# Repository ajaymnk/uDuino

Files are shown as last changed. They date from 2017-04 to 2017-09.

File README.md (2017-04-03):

# uDuino
Arduino compatible AVR Development Board

#### Top Layer
<p align="center">
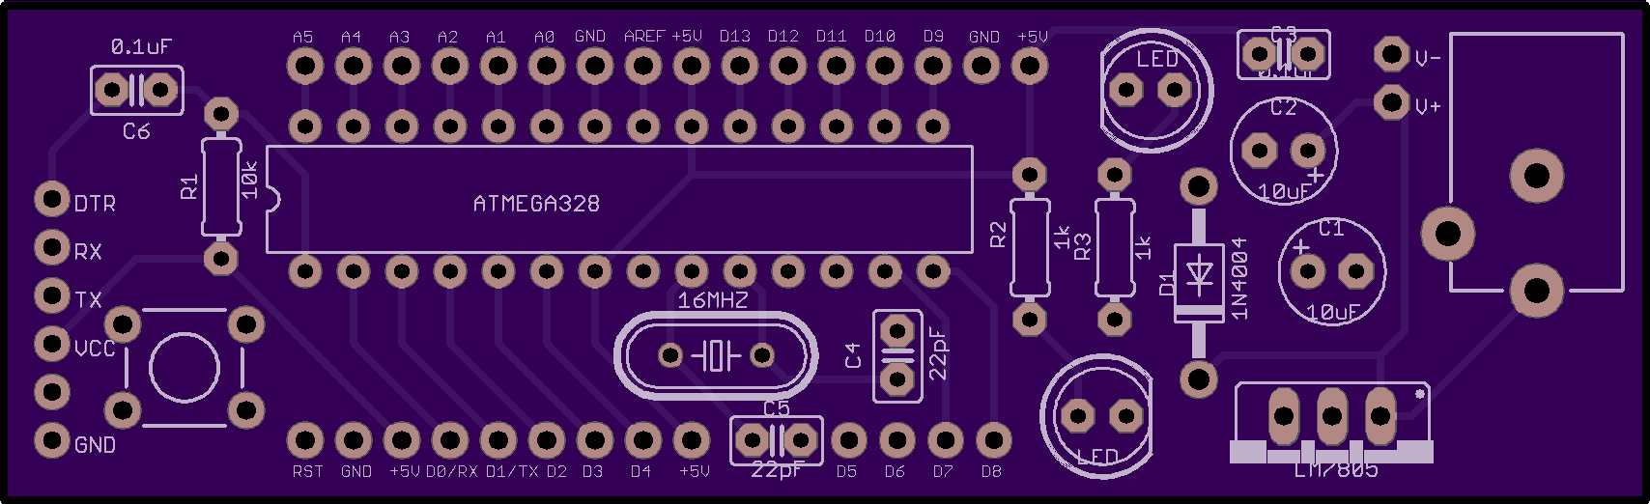
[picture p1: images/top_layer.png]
Top Layer

</p>

#### Bottom Layer
<p align="center">
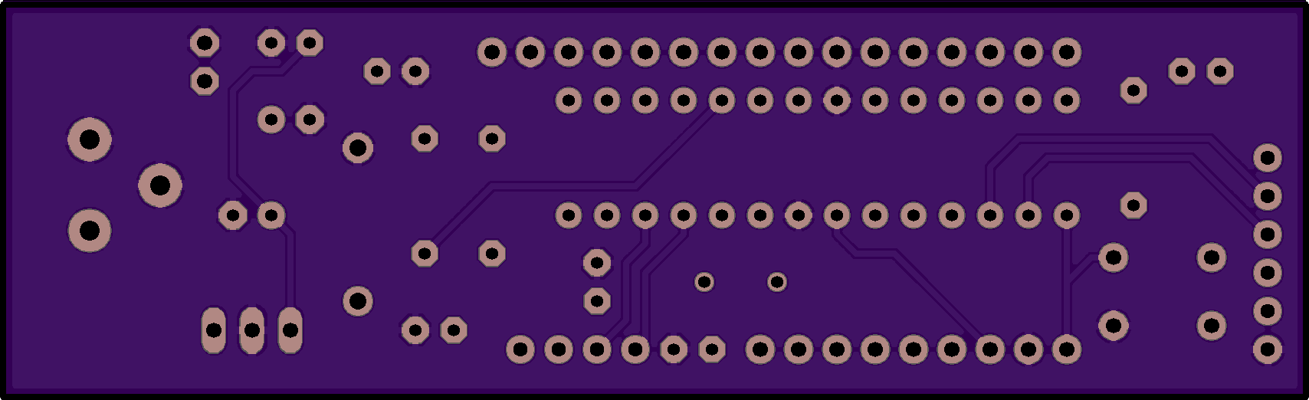
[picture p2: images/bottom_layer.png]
Bottom Layer

</p>

#### 3D View
<a href="https://sketchfab.com/models/0a4b825f3d744794a45e6b6fafa52535">
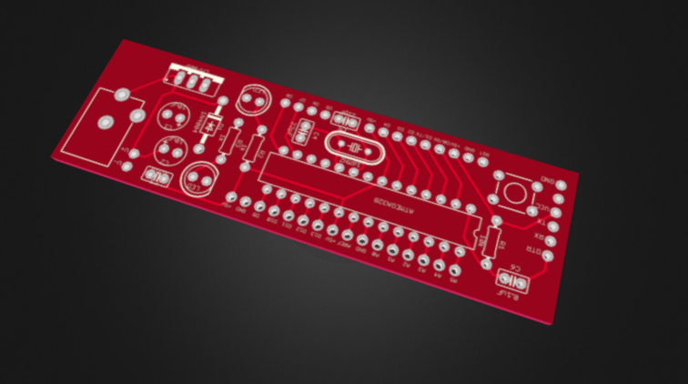
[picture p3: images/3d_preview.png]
3D View
</a>

---
#### Want to order the board


## License
[Creative Commons Attribution Share Alike 4.0](https://creativecommons.org/licenses/by-sa/4.0/)

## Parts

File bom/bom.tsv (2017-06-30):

References | Qty | Description | Manufacturer | MPN | Manufacturer | MPN | Digikey | Mouser | Newark | Farnell
S1 | 1 | Pushbutton Switch | Panasonic | EVQ-PAG07K | TE Connectivity | FSM5JH | P12196S-ND | EVQ-PAG07K | 52W2478 | 2610954
IC1 | 1 | LM7805 Voltage Regulator | Fairchild Semiconductor | LM7805ACT |  |  | LM7805ACT-ND | LM7805ACT | 86K1590 | 2296047
Q1 | 1 | 16mhz Crystal | Fox Electronics | FOXSLF/160-20 | MULTICOMP | HC49S-16-30-50-70-30-ATF | 631-1108-ND | FOXSLF/160-20 | 58T1826 | 1667003
IC2 | 1 | ATMEGA328P | Microchip | ATMEGA328-PU |  |  | ATMEGA328-PU-ND | ATMEGA328-PU | 68T2932 | 1972087
D1 | 1 | 1N4004 Diode | ON Semiconductor | 1N4004G |  |  | 1N4004GOS-ND | 863-1N4004G | 42K2822 | 1651084
C1, C2 | 2 | 10 uf Electrolytic Capacitor | Panasonic | ECE-A1VKS100 |  |  | P980-ND | ECE-A1VKS100 | 55T0262 | 1902010
R2, R3 | 2 | 1k Resistor | Panasonic | ERG-1SJ102 |  |  | P1.0KW-1BK-ND | ERG-1SJ102 | 52W6823 | 2324488
J1 | 1 | DC Power Jack | Switchcraft | RAPC712BK |  |  | SC1863-ND | RAPC712BK | 03M4244 | 2579769
JP1, JP2, JP3, JP4, JP5 | 1 | Single row Male headers | TE Connectivity | 5-826947-0 | TE Connectivity | 5-825433-0 | A105203-ND | 5-826947-0 | 98K9591 | 1580058
C4, C5 | 2 | 22pf Ceramic Capacitor | Vishay BCcomponents | S220K25SL0N63L6R | MULTICOMP | MCCHU5220J5 | 1270PH-ND | S220K25SL0N63L6R | 92K9515 | 9411674
C3, C6 | 2 | 0.1 uf Ceramic Capacitor | Vishay | K104K10X7RF5UH5 | MULTICOMP | MCCC50V104KY5P | BC2665CT-ND | K104K10X7RF5UH5 | 97M4053 | 2507749
R1 | 1 | 10k Resistor | Vishay | MRS25000C1002FCT00 | MULTICOMP | MCF 1W 10K | BC3326CT-ND | MRS25000C1002FCT00 | 38K0401 | 9463976
LED1, LED2 | 2 | LED 5MM | Vishay | TLUV5300 |  |  | TLUV5300-ND | TLUV5300 | 33C1443 | 1045375

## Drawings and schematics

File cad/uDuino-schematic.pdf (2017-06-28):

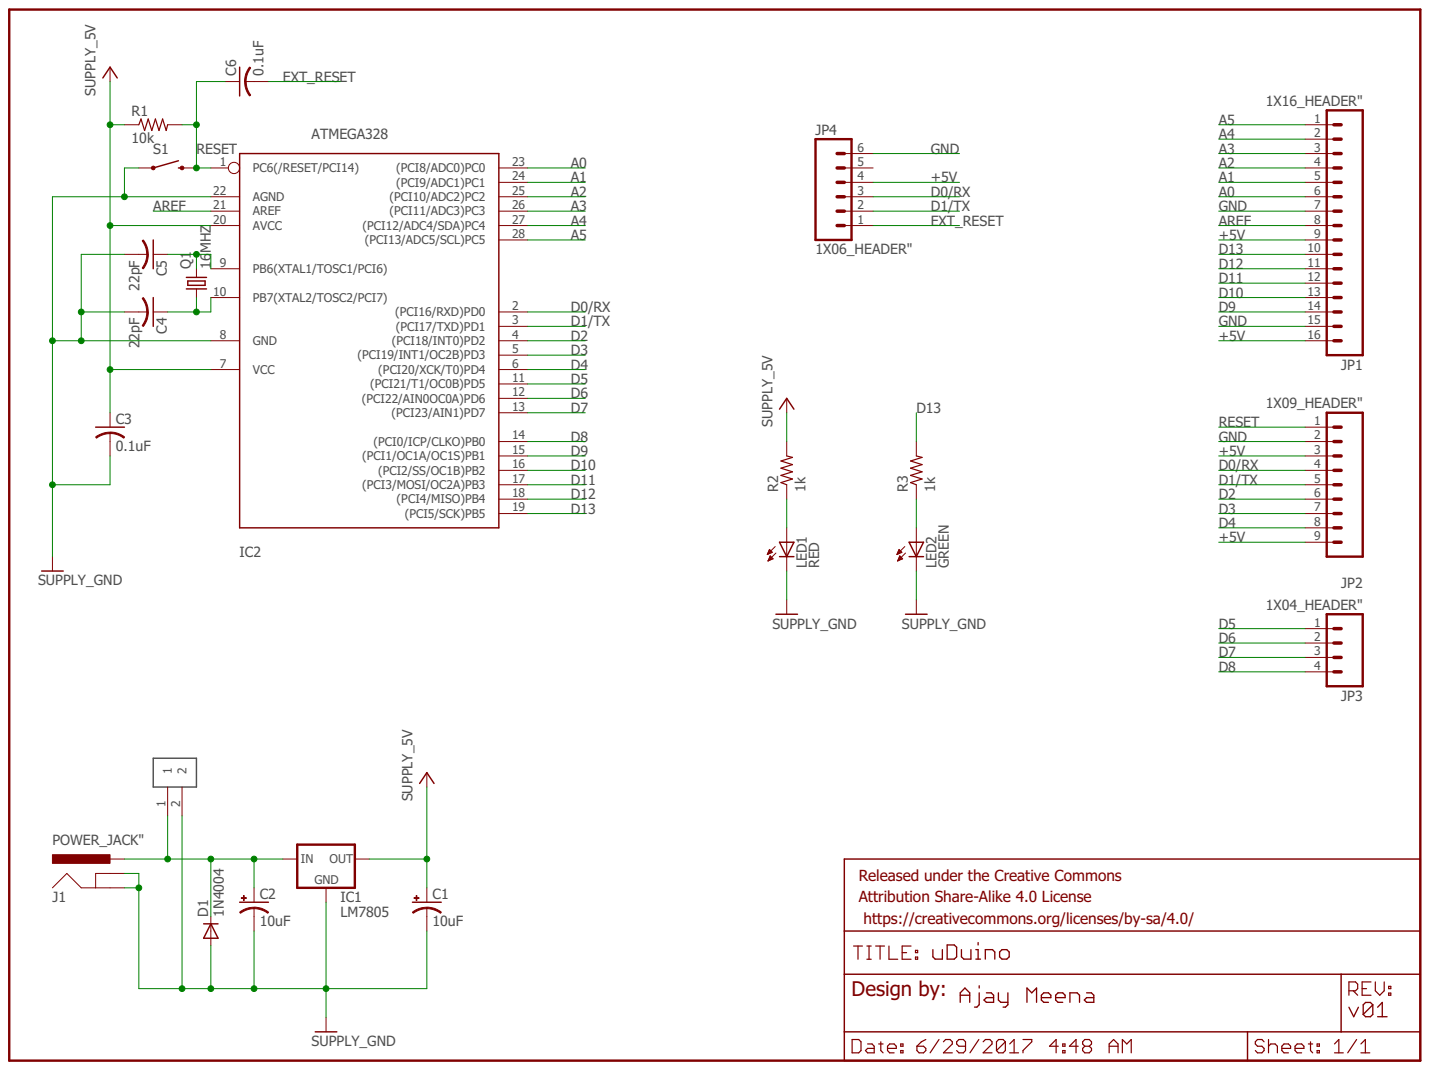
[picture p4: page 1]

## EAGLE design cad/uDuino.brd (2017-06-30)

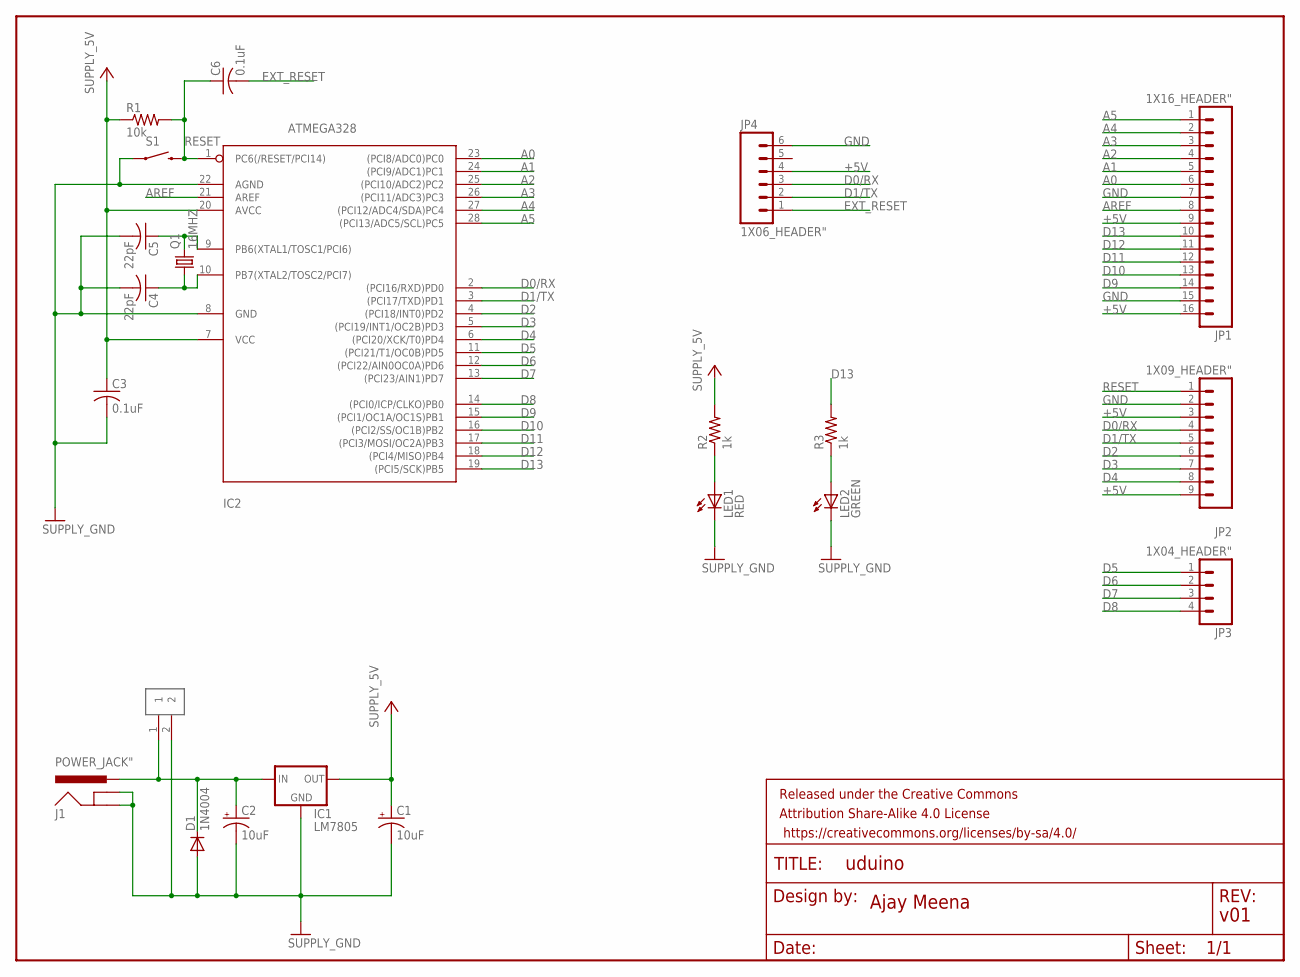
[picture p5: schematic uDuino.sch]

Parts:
C1, C2: 10uF; ELECTROLYTIC_CAP
C3, C6: 0.1uF; UNPOLARIZED_CAP
C4, C5: 22pF; UNPOLARIZED_CAP
D1: 1N4004; DO41-10
FRAME1: FRAME-LETTERNO_PACKAGE; DUMMY
IC1: LM7805; L4931_REGULATOR
IC2: ATMEGA328
J1: POWER_JACK"; POWER_JACK
JP1: 1X16_HEADER"; 1X16_HEADER
JP2: 1X09_HEADER"; 1X09_HEADER
JP3: 1X04_HEADER"; 1X04_HEADER
JP4: 1X06_HEADER"; 1X06_HEADER
JP5: 1X02_HEADER
LED1: RED; LED5MM
LED2: GREEN; LED5MM
Q1: 16MHZ; HC49/S
R1: 10k; 0204/7
R2, R3: 1k; 0204/7
S1: MOMENTARY_SWITCH"; MOMENTARY_SWITCH

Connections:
+5V: C1.+, C3.1, IC1.OUT, IC2.7 (VCC), IC2.20 (AVCC), JP1.9, JP1.16, JP2.3, JP2.9, JP4.4, R1.1, R2.2
A0: IC2.23 ((PCI8/ADC0)PC0), JP1.6
A1: IC2.24 ((PCI9/ADC1)PC1), JP1.5
A2: IC2.25 ((PCI10/ADC2)PC2), JP1.4
A3: IC2.26 ((PCI11/ADC3)PC3), JP1.3
A4: IC2.27 ((PCI12/ADC4/SDA)PC4), JP1.2
A5: IC2.28 ((PCI13/ADC5/SCL)PC5), JP1.1
AREF: IC2.21 (AREF), JP1.8
D0/RX: IC2.2 ((PCI16/RXD)PD0), JP2.4, JP4.3
D1/TX: IC2.3 ((PCI17/TXD)PD1), JP2.5, JP4.2
D2: IC2.4 ((PCI18/INT0)PD2), JP2.6
D3: IC2.5 ((PCI19/INT1/OC2B)PD3), JP2.7
D4: IC2.6 ((PCI20/XCK/T0)PD4), JP2.8
D5: IC2.11 ((PCI21/T1/OC0B)PD5), JP3.1
D6: IC2.12 ((PCI22/AIN0OC0A)PD6), JP3.2
D7: IC2.13 ((PCI23/AIN1)PD7), JP3.3
D8: IC2.14 ((PCI0/ICP/CLKO)PB0), JP3.4
D9: IC2.15 ((PCI1/OC1A/OC1S)PB1), JP1.14
D10: IC2.16 ((PCI2/SS/OC1B)PB2), JP1.13
D11: IC2.17 ((PCI3/MOSI/OC2A)PB3), JP1.12
D12: IC2.18 ((PCI4/MISO)PB4), JP1.11
D13: IC2.19 ((PCI5/SCK)PB5), JP1.10, R3.2
EXT_RESET: C6.2, JP4.1
GND: C1.-, C2.-, C3.2, C4.2, C5.2, D1.A, IC1.GND, IC2.8 (GND), IC2.22 (AGND), J1.GND, J1.GNDBREAK, JP1.7, JP1.15, JP2.2, JP4.6, JP5.2, LED1.K (C), LED2.K (C), S1.1
unnamed: C2.+, D1.C, IC1.IN, J1.PWR, JP5.1
unnamed: C5.1, IC2.9 (PB6(XTAL1/TOSC1/PCI6)), Q1.2
unnamed: C4.1, IC2.10 (PB7(XTAL2/TOSC2/PCI7)), Q1.1
unnamed: LED2.A, R3.1
unnamed: LED1.A, R2.1
RESET: C6.1, IC2.1 (PC6(/RESET/PCI14)), JP2.1, R1.2, S1.3 (2)

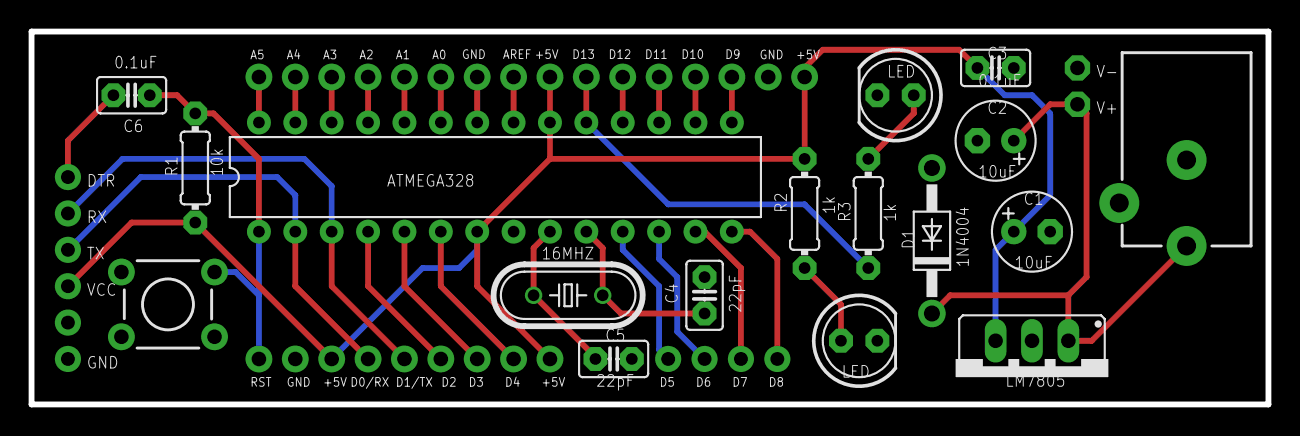
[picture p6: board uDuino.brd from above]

Board: 2 copper layers, 86.4 x 26.0 mm, 23 parts (0 on the bottom side), 30 nets.

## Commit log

2017-02-22 Added LED at D13
    [uDuino.brd, uDuino.sch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]
2017-03-12 renamed uDuino.pdf to uDuino-silkscreen.pdf
2017-06-28 changed frame
    [uDuino.brd, uDuino.sch]
2017-06-29 Added gerber files
2017-06-30 Adding project to kitnic.it
    [bom.tsv, uDuino.brd, uDuino.sch]
2017-06-30 Improve bom part selection a little
    [bom.tsv]
2017-06-30 Updated Newark and Farnell carts
    Added alternative parts for US and UK only stock
    [bom.tsv]

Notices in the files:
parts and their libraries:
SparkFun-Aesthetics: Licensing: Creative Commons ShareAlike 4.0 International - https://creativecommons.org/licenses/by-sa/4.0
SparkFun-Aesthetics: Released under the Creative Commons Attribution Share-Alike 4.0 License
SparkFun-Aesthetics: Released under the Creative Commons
